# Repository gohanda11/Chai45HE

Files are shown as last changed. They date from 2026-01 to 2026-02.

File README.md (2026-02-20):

# Chai45HE

Chai45HE is a 40% Hall-effect keyboard based on the [HE60](https://github.com/peppapighs/HE60) project. This is a modified version that adapts the original 60% design to a compact 40% layout.

## Key Features

- 40% compact layout
- Hall-effect magnetic switches support
- Based on HE60's proven design and technology
- Custom PCB design files included

## ファームウェアの書き込み方法

1. [firmware.bin](firmware/firmware.bin) をダウンロードします。
2. 基板裏側の **BOOT** ボタンを長押ししながらUSBケーブルを接続し、Bootloader Modeに入ります。
3. [WebDFU](https://devanlai.github.io/webdfu/dfu-util/) にアクセスし、**DFU in FS mode** に接続します。
4. **Firmware Download** セクションでダウンロードした `firmware.bin` ファイルを選択します。
5. **Download** ボタンを押して書き込みを実行します。

## キー設定ガイド

### Tap-Holdの設定方法

Tap-Holdを使うと、短押し(Tap)と長押し(Hold)で異なるキーを割り当てることができます。

1. Remapで **Tap** に設定したいキーを配置します。
2. **Advanced Keys** から **Tap-Hold** を選択します。
3. **Hold** に設定したいキーを選択し、**Continue** を押します。
4. Hold用のキーを設定して **Done** で設定完了です。

### !@#$%などの記号キーの設定方法

Shiftキーとの組み合わせで入力される記号(!@#$%など)を単独のキーとして設定する方法です。

1. Remapで `1 2 3 4 5` を、`! @ # $ %` を入力したいキーに設定します。
2. **Advanced Keys** から **Dynamic Keystroke** を選択します。
3. 下の画像のようにShiftを割り当てます。

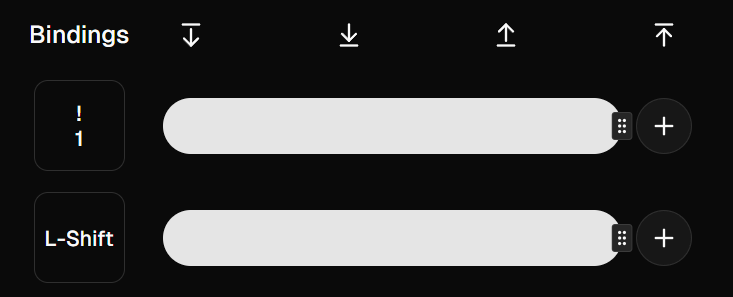
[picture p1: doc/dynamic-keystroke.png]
Dynamic Keystrokeの設定例
   

4. **Done** で設定完了です。

---

# HE60 (Original Project)

Below is the original README from the HE60 project, which this keyboard is based on.

---

# HE60

HE60 is a 60% Hall-effect keyboard PCB with 8kHz polling rate, a split spacebar and Tsangan layout support.

## Features

- Support for GH60 tray mount cases e.g., KBDfans Tofu60 Redux, and KBDfans Holy60.
- Support for gummy O-ring mount cases **if the USB-C port is not soldered** e.g., Bakeneko60, and SingaKBD Unikorn (required 10mm JST cable).
- [libhmk](https://github.com/peppapighs/libhmk) firmware.
- [hmkconf](https://hmk.prasertsuk.com) web-based configurator.

## Disclaimer

- The PCB requires standoffs to be mounted to the switch plate. The mounting points are **not compatible** with other available plates e.g., GEON Venom60 7U plate. HE60 v1 plate **is not compatible** with this PCB.

## Supported Layouts

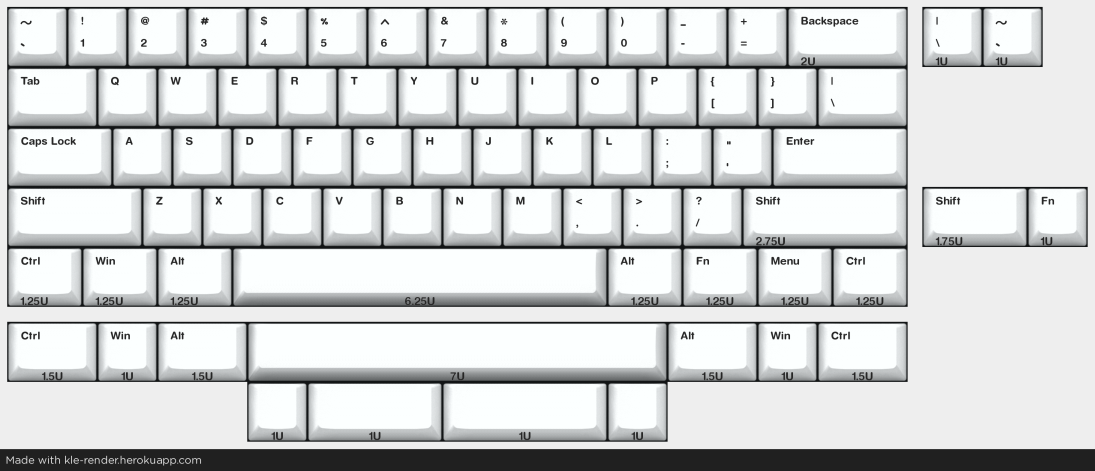
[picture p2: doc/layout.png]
Layouts


## Fabrication

The following files are required:

- BOM (Bill of Materials): Contains the list of components required to build the PCB.
- Pick and Place: Contains the placement of the components on the PCB.
- Gerber: Contains the PCB design files for fabrication.

Note that the components in the BOM are all mounted on the bottom side of the PCB, and are based on the available components in JLCPCB at the time of writing. You may need to adjust the components based on your preference or availability. For the JST connector (labeled `JST_SH`), I used `WAFER-SH1.0-4PWB` offered by JLCPCB. **Make sure to deselect the USB-C port when choosing the components to solder if you are using the gummy O-ring version.**

You may change the Hall-effect sensors during the component selection based on your preference, and availability. Different sensors require different calibration values, which can be adjusted using the web-based configurator. Here are some options that I have used:

- GH39FKSW (Cheapest)
- MT9102ET
- SS39ET
- DRV5055A3
- OH49E-S (Discontinued)

The fabrication files above are available [here](https://github.com/peppapighs/HE60/releases).

## Build Guide

The following items are required to build the PCB:

- PCB
- Switch plate (DXF file available [here](/plate.dxf). You may need to use less flexible materials such as aluminum or FR4 to prevent the switch at the top right corner from popping out if you use the alternative backspace layout. If you would like to manufacture FR4 plate along with the PCB, you can find the GERBER file for the plate [here](https://github.com/peppapighs/HE60/releases).)
- Magnetic switches (e.g., GEON Raw HE, Gateron Magnetic Jade, Duhuk Core HE, etc.)
- Stabilizers (**Clip-in stabilizers are required for the gummy O-ring version**)
- M2 3.5mm standoffs x8
- M2 3mm flat head screws x16

1. Install the stabilizers to the PCB.

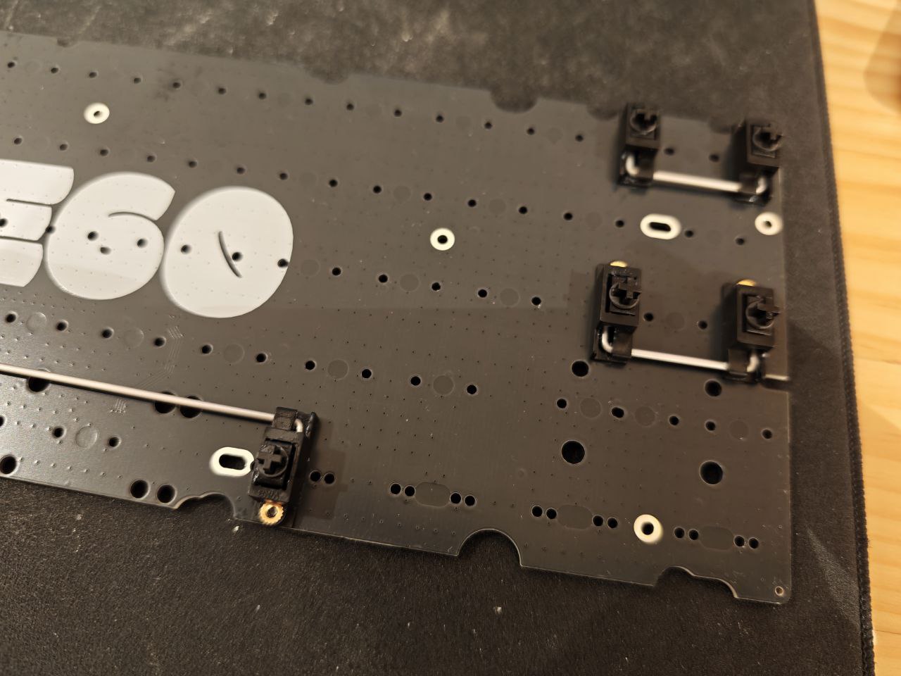
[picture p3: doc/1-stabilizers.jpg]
Stabilizers


2. Attach the standoffs to the PCB using the M2 screws.

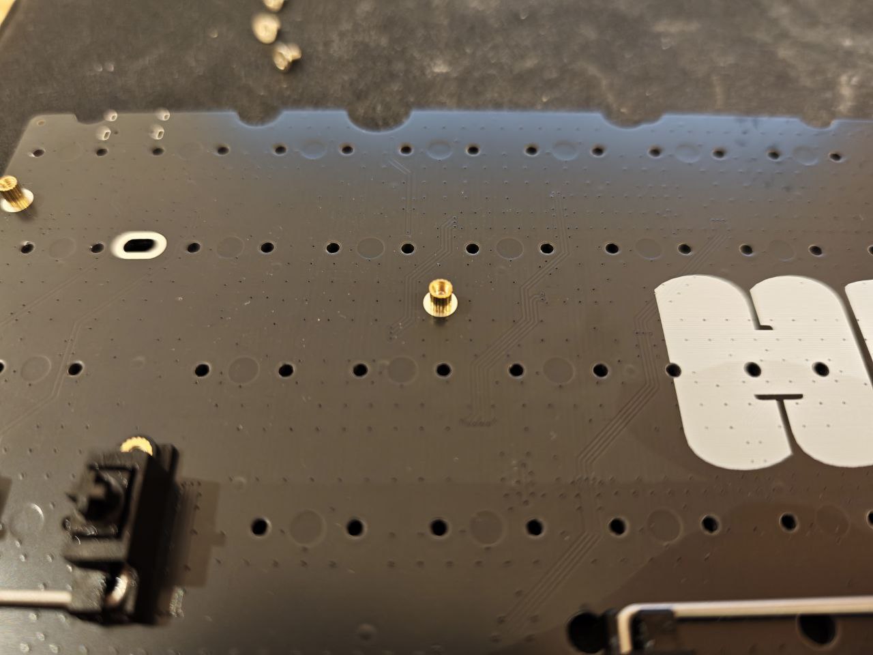
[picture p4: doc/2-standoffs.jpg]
Standoff


3. Install the switches to the plate. Assemble the plate and PCB together. Press the PCB against the plate to make sure the switches are seated properly. Screw the standoffs to the plate using the rest of the M2 screws.

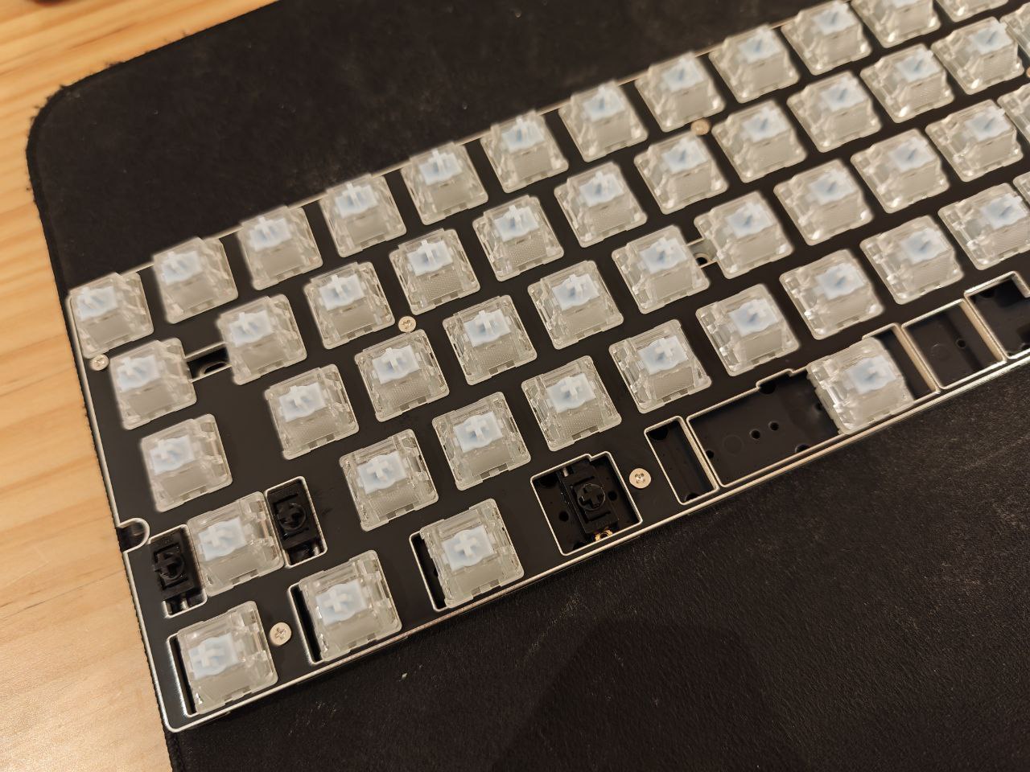
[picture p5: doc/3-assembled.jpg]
Assembled


4. Install the PCB into the case.

Case with keycaps

## Firmware

Head to [libhmk](https://github.com/peppapighs/libhmk/releases) for a pre-compiled firmware. The firmware can be flashed using DFU mode, which can be entered by holding the BOOT button before plugging in. You may need to install the DFU bootloader driver using Zadig. See [libhmk](https://github.com/peppapighs/libhmk) for more information for firmware flashing instructions.

## Acknowledgements

- Xelus from AEBoards for reviewing the PCB design and providing feedback.
- Keyboard Atelier community for supporting the project.

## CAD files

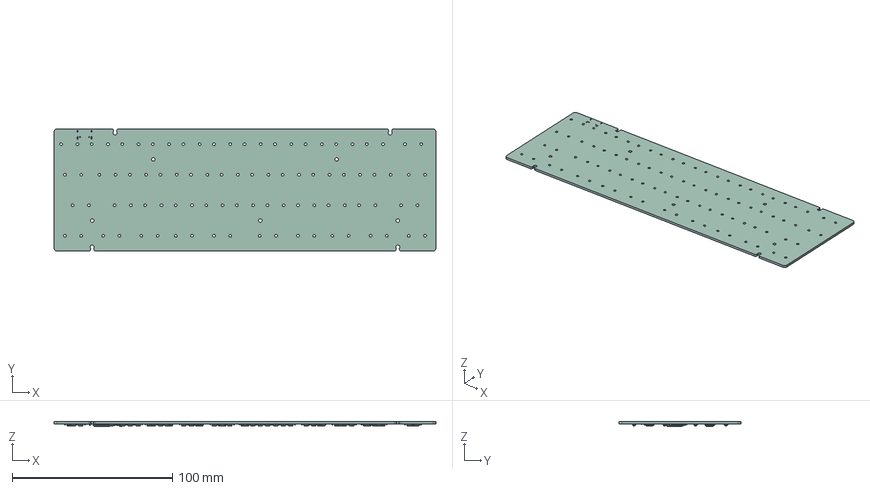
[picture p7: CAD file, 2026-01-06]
Chai45HE/Chai45HE.step
238.1 x 76.2 x 3.15 mm
SOT-23-3 x 46
C_0402_1005Metric x 101
LQFP-64_10x10mm_P0.5mm
TSSOP-16_4.4x5mm_P0.65mm x 6
C_0603_1608Metric x 8
R_0402_1005Metric x 4
Fuse_0805_2012Metric
SOT-23-5
Crystal_SMD_3225-4Pin_3.2x2.5mm
SOT-23-6
Chai45HE_PCB

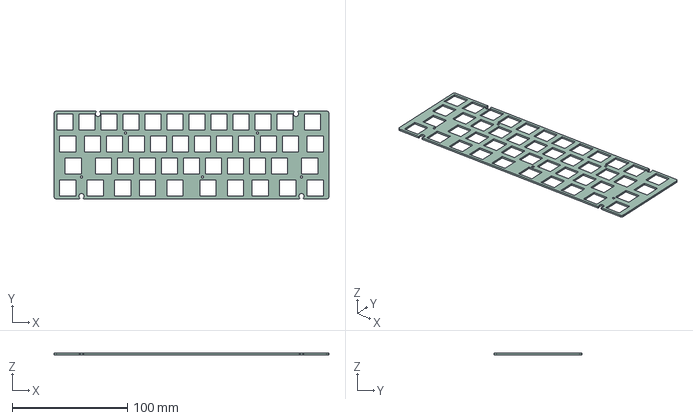
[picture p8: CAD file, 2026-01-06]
plate/switch/switch_plate.stp
238.1 x 76.2 x 1.50 mm

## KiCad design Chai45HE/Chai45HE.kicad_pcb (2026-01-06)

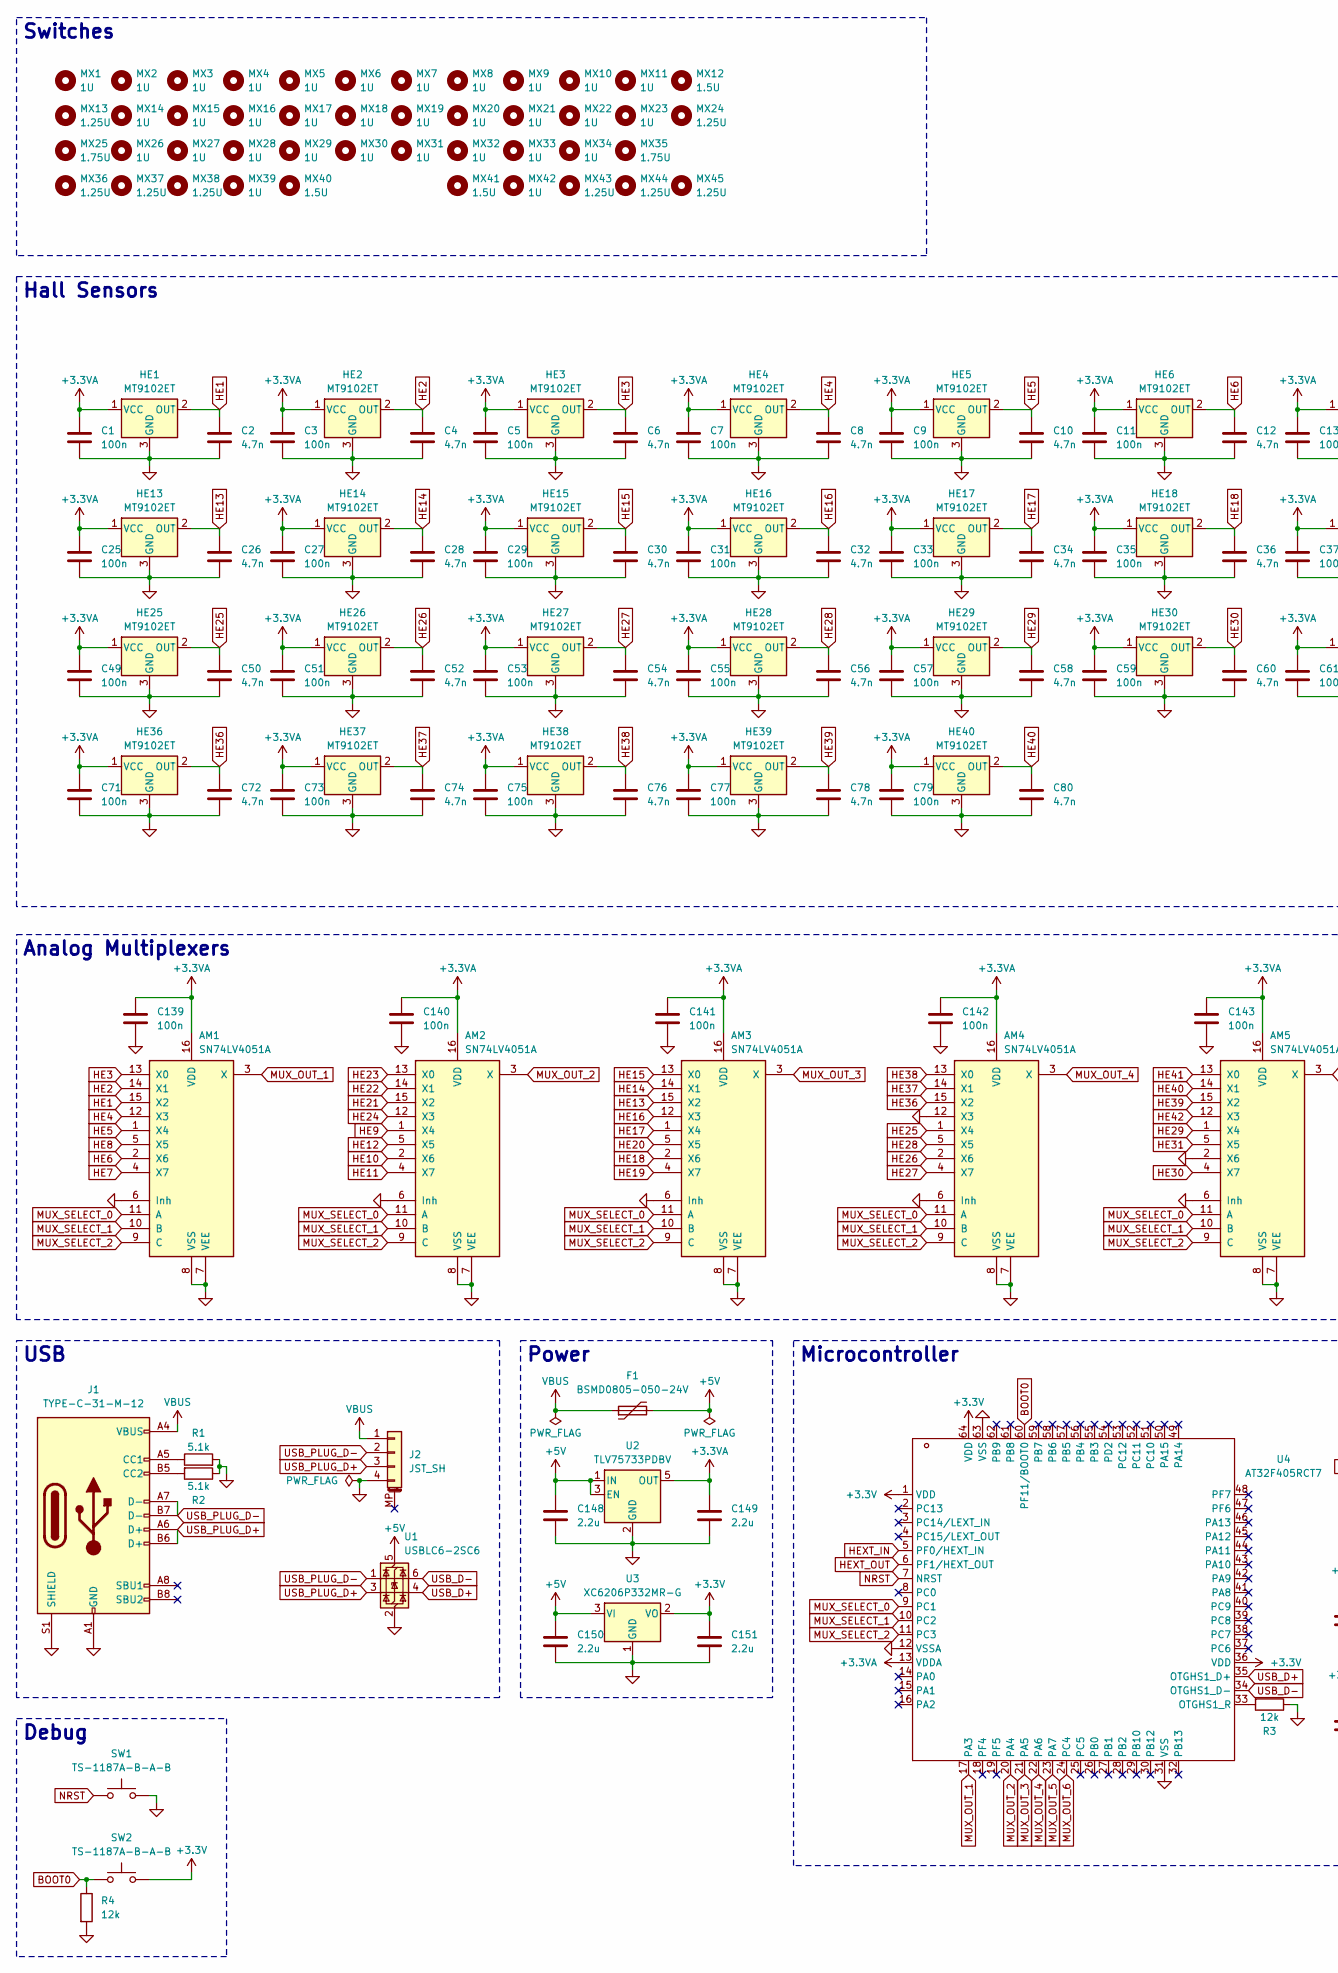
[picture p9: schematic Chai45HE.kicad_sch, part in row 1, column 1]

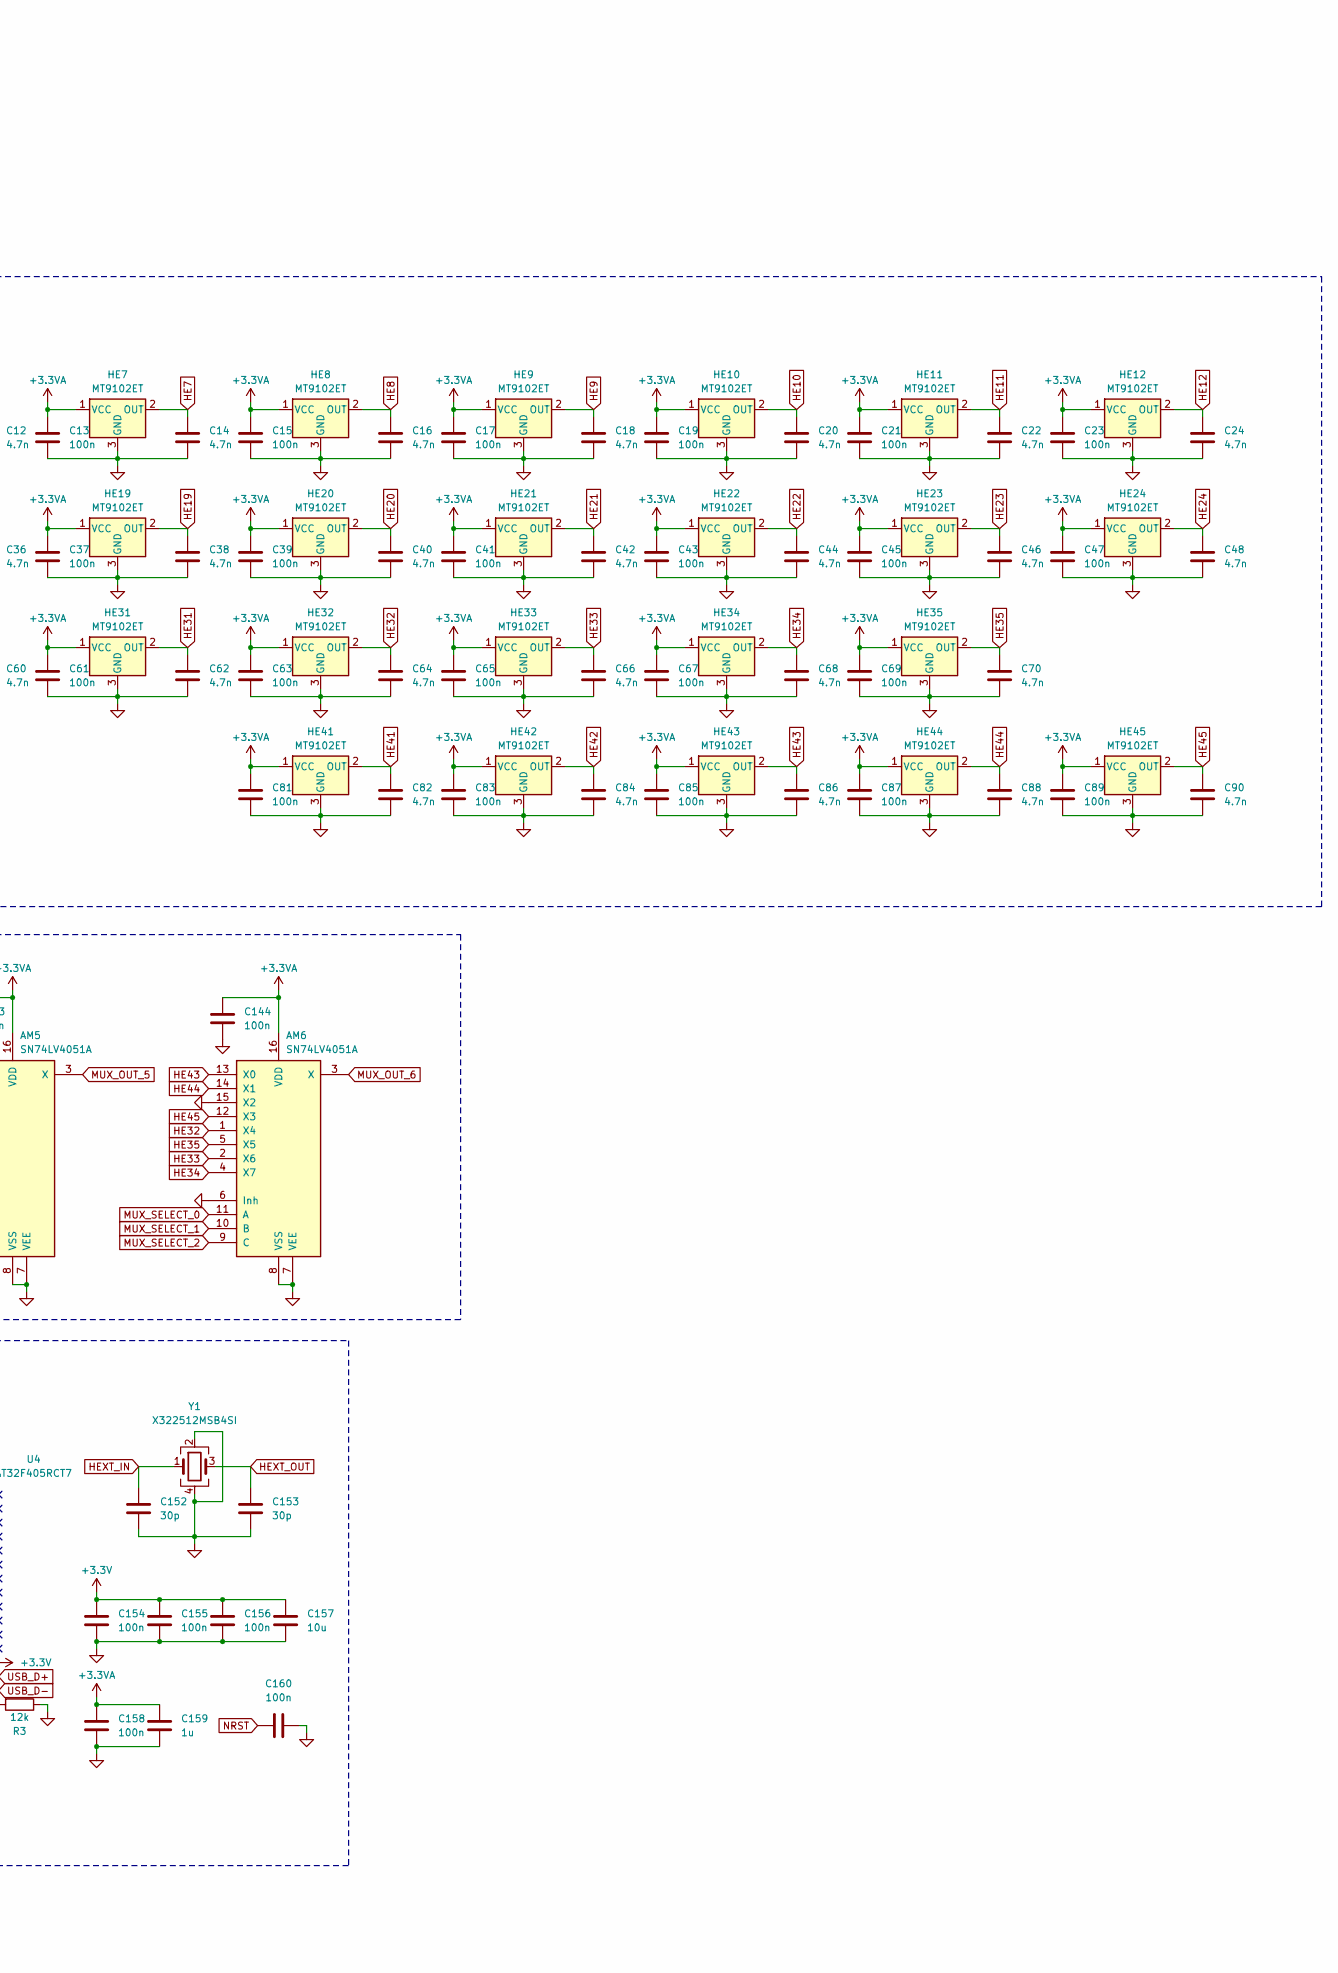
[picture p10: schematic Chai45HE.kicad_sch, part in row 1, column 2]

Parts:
AM1, AM2, AM3, AM4, AM5, AM6: SN74LV4051A; TSSOP-16_4.4x5mm_P0.65mm
C1, C3, C5, C7, C9, C11, C13, C15, C17, C19, C21, C23, C25, C27, C29, C31, C33, C35, C37, C39, C41, C43, C45, C47, C49, C51, C53, C55, C57, C59, C61, C63, C65, C67, C69, C71, C73, C75, C77, C79, C81, C83, C85, C87, C89, C139, C140, C141, C142, C143, C144, C154, C155, C156, C158, C160: 100n; C_0402_1005Metric
C2, C4, C6, C8, C10, C12, C14, C16, C18, C20, C22, C24, C26, C28, C30, C32, C34, C36, C38, C40, C42, C44, C46, C48, C50, C52, C54, C56, C58, C60, C62, C64, C66, C68, C70, C72, C74, C76, C78, C80, C82, C84, C86, C88, C90: 4.7n; C_0402_1005Metric
C148, C149, C150, C151: 2.2u; C_0603_1608Metric
C152, C153: 30p; C_0603_1608Metric
C157: 10u; C_0603_1608Metric
C159: 1u; C_0603_1608Metric
F1: BSMD0805-050-24V; Fuse_0805_2012Metric
HE1, HE2, HE3, HE4, HE5, HE6, HE7, HE8, HE9, HE10, HE11, HE12, HE13, HE14, HE15, HE16, HE17, HE18, HE19, HE20, HE21, HE22, HE23, HE24, HE25, HE26, HE27, HE28, HE29, HE30, HE31, HE32, HE33, HE34, HE35, HE36, HE37, HE38, HE39, HE40, HE41, HE42, HE43, HE44, HE45: MT9102ET; SOT-23-3
J1: TYPE-C-31-M-12; USB_C_Receptacle_HRO_TYPE-C-31-M-12
J2: JST_SH; JST_SH_SM04B-SRSS-TB_1x04-1MP_P1.00mm_Horizontal
MX1, MX2, MX3, MX4, MX5, MX6, MX7, MX8, MX9, MX10, MX11, MX14, MX15, MX16, MX17, MX18, MX19, MX20, MX21, MX22, MX23, MX26, MX27, MX28, MX29, MX30, MX31, MX32, MX33, MX34, MX39, MX42: 1U; MX-1U
MX12, MX40, MX41: 1.5U; MX-1.5U
MX13, MX24, MX36, MX37, MX38, MX43, MX44, MX45: 1.25U; MX-1.25U
MX25, MX35: 1.75U; MX-1.75U
R1, R2: 5.1k; R_0402_1005Metric
R3, R4: 12k; R_0402_1005Metric
SW1, SW2: TS-1187A-B-A-B; SW_Push_1P1T_XKB_TS-1187A
U1: USBLC6-2SC6; SOT-23-6
U2: TLV75733PDBV; SOT-23-5
U3: XC6206P332MR-G; SOT-23-3
U4: AT32F405RCT7; LQFP-64_10x10mm_P0.5mm
Y1: X322512MSB4SI; Crystal_SMD_3225-4Pin_3.2x2.5mm

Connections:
+3.3V: C151.1, C154.1, C155.1, C156.1, C157.1, SW2.2, U3.2 (VO), U4.1 (VDD), U4.36 (VDD), U4.64 (VDD)
+3.3VA: AM1.16 (VDD), AM2.16 (VDD), AM3.16 (VDD), AM4.16 (VDD), AM5.16 (VDD), AM6.16 (VDD), C1.1, C3.1, C5.1, C7.1, C9.1, C11.1, C13.1, C15.1, C17.1, C19.1, C21.1, C23.1, C25.1, C27.1, C29.1, C31.1, C33.1, C35.1, C37.1, C39.1, C41.1, C43.1, C45.1, C47.1, C49.1, C51.1, C53.1, C55.1, C57.1, C59.1, C61.1, C63.1, C65.1, C67.1, C69.1, C71.1, C73.1, C75.1, C77.1, C79.1, C81.1, C83.1, C85.1, C87.1, C89.1, C139.1, C140.1, C141.1, C142.1, C143.1, C144.1, C149.1, C158.1, C159.1, HE1.1 (VCC), HE2.1 (VCC), HE3.1 (VCC), HE4.1 (VCC), HE5.1 (VCC), HE6.1 (VCC), HE7.1 (VCC), HE8.1 (VCC), HE9.1 (VCC), HE10.1 (VCC), HE11.1 (VCC), HE12.1 (VCC), HE13.1 (VCC), HE14.1 (VCC), HE15.1 (VCC), HE16.1 (VCC), HE17.1 (VCC), HE18.1 (VCC), HE19.1 (VCC), HE20.1 (VCC), HE21.1 (VCC), HE22.1 (VCC), HE23.1 (VCC), HE24.1 (VCC), HE25.1 (VCC), HE26.1 (VCC), HE27.1 (VCC), HE28.1 (VCC), HE29.1 (VCC), HE30.1 (VCC), HE31.1 (VCC), HE32.1 (VCC), HE33.1 (VCC), HE34.1 (VCC), HE35.1 (VCC), HE36.1 (VCC), HE37.1 (VCC), HE38.1 (VCC), HE39.1 (VCC), HE40.1 (VCC), HE41.1 (VCC), HE42.1 (VCC), HE43.1 (VCC), HE44.1 (VCC), HE45.1 (VCC), U2.5 (OUT), U4.13 (VDDA)
+5V: C148.1, C150.1, F1.2, U1.5 (VBUS), U2.1 (IN), U2.3 (EN), U3.3 (VI)
BOOT0: R4.1, SW2.1, U4.60 (PF11/BOOT0)
GND: AM1.6 (Inh), AM1.7 (VEE), AM1.8 (VSS), AM2.6 (Inh), AM2.7 (VEE), AM2.8 (VSS), AM3.6 (Inh), AM3.7 (VEE), AM3.8 (VSS), AM4.6 (Inh), AM4.7 (VEE), AM4.8 (VSS), AM4.12 (X3), AM5.2 (X6), AM5.6 (Inh), AM5.7 (VEE), AM5.8 (VSS), AM6.6 (Inh), AM6.7 (VEE), AM6.8 (VSS), AM6.15 (X2), C1.2, C2.2, C3.2, C4.2, C5.2, C6.2, C7.2, C8.2, C9.2, C10.2, C11.2, C12.2, C13.2, C14.2, C15.2, C16.2, C17.2, C18.2, C19.2, C20.2, C21.2, C22.2, C23.2, C24.2, C25.2, C26.2, C27.2, C28.2, C29.2, C30.2, C31.2, C32.2, C33.2, C34.2, C35.2, C36.2, C37.2, C38.2, C39.2, C40.2, C41.2, C42.2, C43.2, C44.2, C45.2, C46.2, C47.2, C48.2, C49.2, C50.2, C51.2, C52.2, C53.2, C54.2, C55.2, C56.2, C57.2, C58.2, C59.2, C60.2, C61.2, C62.2, C63.2, C64.2, C65.2, C66.2, C67.2, C68.2, C69.2, C70.2, C71.2, C72.2, C73.2, C74.2, C75.2, C76.2, C77.2, C78.2, C79.2, C80.2, C81.2, C82.2, C83.2, C84.2, C85.2, C86.2, C87.2, C88.2, C89.2, C90.2, C139.2, C140.2, C141.2, C142.2, C143.2, C144.2, C148.2, C149.2, C150.2, C151.2, C152.2, C153.2, C154.2, C155.2, C156.2, C157.2, C158.2, C159.2, C160.2, HE1.3 (GND), HE2.3 (GND), HE3.3 (GND), HE4.3 (GND), HE5.3 (GND), HE6.3 (GND), HE7.3 (GND), HE8.3 (GND), HE9.3 (GND), HE10.3 (GND), HE11.3 (GND), HE12.3 (GND), HE13.3 (GND), HE14.3 (GND), HE15.3 (GND), HE16.3 (GND), HE17.3 (GND), HE18.3 (GND), HE19.3 (GND), HE20.3 (GND), HE21.3 (GND), HE22.3 (GND), HE23.3 (GND), HE24.3 (GND), HE25.3 (GND), HE26.3 (GND), HE27.3 (GND), HE28.3 (GND), HE29.3 (GND), HE30.3 (GND), HE31.3 (GND), HE32.3 (GND), HE33.3 (GND), HE34.3 (GND), HE35.3 (GND), HE36.3 (GND), HE37.3 (GND), HE38.3 (GND), HE39.3 (GND), HE40.3 (GND), HE41.3 (GND), HE42.3 (GND), HE43.3 (GND), HE44.3 (GND), HE45.3 (GND), J1.A1 (GND), J1.A12 (GND), J1.B1 (GND), J1.B12 (GND), J1.S1 (SHIELD), J2.4, R1.2, R2.1, R3.1, R4.2, SW1.2, U1.2 (GND), U2.2 (GND), U3.1 (GND), U4.12 (VSSA), U4.31 (VSS), U4.63 (VSS), Y1.2, Y1.4
HE1: AM1.15 (X2), C2.1, HE1.2 (OUT)
HE2: AM1.14 (X1), C4.1, HE2.2 (OUT)
HE3: AM1.13 (X0), C6.1, HE3.2 (OUT)
HE4: AM1.12 (X3), C8.1, HE4.2 (OUT)
HE5: AM1.1 (X4), C10.1, HE5.2 (OUT)
HE6: AM1.2 (X6), C12.1, HE6.2 (OUT)
HE7: AM1.4 (X7), C14.1, HE7.2 (OUT)
HE8: AM1.5 (X5), C16.1, HE8.2 (OUT)
HE9: AM2.1 (X4), C18.1, HE9.2 (OUT)
HE10: AM2.2 (X6), C20.1, HE10.2 (OUT)
HE11: AM2.4 (X7), C22.1, HE11.2 (OUT)
HE12: AM2.5 (X5), C24.1, HE12.2 (OUT)
HE13: AM3.15 (X2), C26.1, HE13.2 (OUT)
HE14: AM3.14 (X1), C28.1, HE14.2 (OUT)
HE15: AM3.13 (X0), C30.1, HE15.2 (OUT)
HE16: AM3.12 (X3), C32.1, HE16.2 (OUT)
HE17: AM3.1 (X4), C34.1, HE17.2 (OUT)
HE18: AM3.2 (X6), C36.1, HE18.2 (OUT)
HE19: AM3.4 (X7), C38.1, HE19.2 (OUT)
HE20: AM3.5 (X5), C40.1, HE20.2 (OUT)
HE21: AM2.15 (X2), C42.1, HE21.2 (OUT)
HE22: AM2.14 (X1), C44.1, HE22.2 (OUT)
HE23: AM2.13 (X0), C46.1, HE23.2 (OUT)
HE24: AM2.12 (X3), C48.1, HE24.2 (OUT)
HE25: AM4.1 (X4), C50.1, HE25.2 (OUT)
HE26: AM4.2 (X6), C52.1, HE26.2 (OUT)
HE27: AM4.4 (X7), C54.1, HE27.2 (OUT)
HE28: AM4.5 (X5), C56.1, HE28.2 (OUT)
HE29: AM5.1 (X4), C58.1, HE29.2 (OUT)
HE30: AM5.4 (X7), C60.1, HE30.2 (OUT)
HE31: AM5.5 (X5), C62.1, HE31.2 (OUT)
HE32: AM6.1 (X4), C64.1, HE32.2 (OUT)
HE33: AM6.2 (X6), C66.1, HE33.2 (OUT)
HE34: AM6.4 (X7), C68.1, HE34.2 (OUT)
HE35: AM6.5 (X5), C70.1, HE35.2 (OUT)
HE36: AM4.15 (X2), C72.1, HE36.2 (OUT)
HE37: AM4.14 (X1), C74.1, HE37.2 (OUT)
HE38: AM4.13 (X0), C76.1, HE38.2 (OUT)
HE39: AM5.15 (X2), C78.1, HE39.2 (OUT)
HE40: AM5.14 (X1), C80.1, HE40.2 (OUT)
HE41: AM5.13 (X0), C82.1, HE41.2 (OUT)
HE42: AM5.12 (X3), C84.1, HE42.2 (OUT)
HE43: AM6.13 (X0), C86.1, HE43.2 (OUT)
HE44: AM6.14 (X1), C88.1, HE44.2 (OUT)
HE45: AM6.12 (X3), C90.1, HE45.2 (OUT)
HEXT_IN: C152.1, U4.5 (PF0/HEXT_IN), Y1.1
HEXT_OUT: C153.1, U4.6 (PF1/HEXT_OUT), Y1.3
MUX_OUT_1: AM1.3 (X), U4.17 (PA3)
MUX_OUT_2: AM2.3 (X), U4.20 (PA4)
MUX_OUT_3: AM3.3 (X), U4.21 (PA5)
MUX_OUT_4: AM4.3 (X), U4.22 (PA6)
MUX_OUT_5: AM5.3 (X), U4.23 (PA7)
MUX_OUT_6: AM6.3 (X), U4.24 (PC4)
MUX_SELECT_0: AM1.11 (A), AM2.11 (A), AM3.11 (A), AM4.11 (A), AM5.11 (A), AM6.11 (A), U4.9 (PC1)
MUX_SELECT_1: AM1.10 (B), AM2.10 (B), AM3.10 (B), AM4.10 (B), AM5.10 (B), AM6.10 (B), U4.10 (PC2)
MUX_SELECT_2: AM1.9 (C), AM2.9 (C), AM3.9 (C), AM4.9 (C), AM5.9 (C), AM6.9 (C), U4.11 (PC3)
NRST: C160.1, SW1.1, U4.7 (NRST)
unnamed: J1.A5 (CC1), R1.1
unnamed: J1.B5 (CC2), R2.2
unnamed: R3.2, U4.33 (OTGHS1_R)
USB_D+: U1.4 (I/O2), U4.35 (OTGHS1_D+)
USB_D-: U1.6 (I/O1), U4.34 (OTGHS1_D-)
USB_PLUG_D+: J1.A6 (D+), J1.B6 (D+), J2.3, U1.3 (I/O2)
USB_PLUG_D-: J1.A7 (D-), J1.B7 (D-), J2.2, U1.1 (I/O1)
VBUS: F1.1, J1.A4 (VBUS), J1.A9 (VBUS), J1.B4 (VBUS), J1.B9 (VBUS), J2.1

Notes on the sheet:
Hall Sensors
Switches
USB
Analog Multiplexers
Power
Debug
Microcontroller

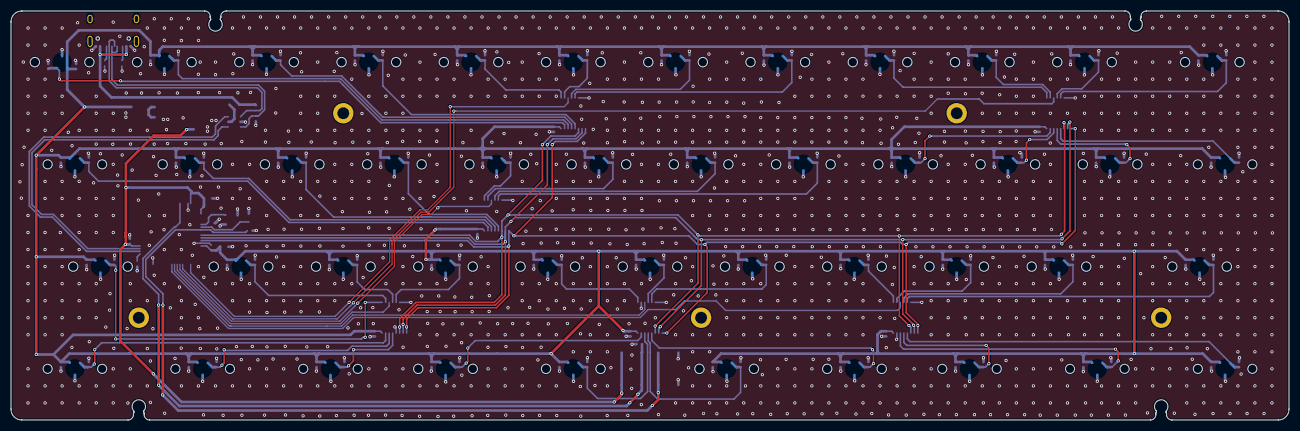
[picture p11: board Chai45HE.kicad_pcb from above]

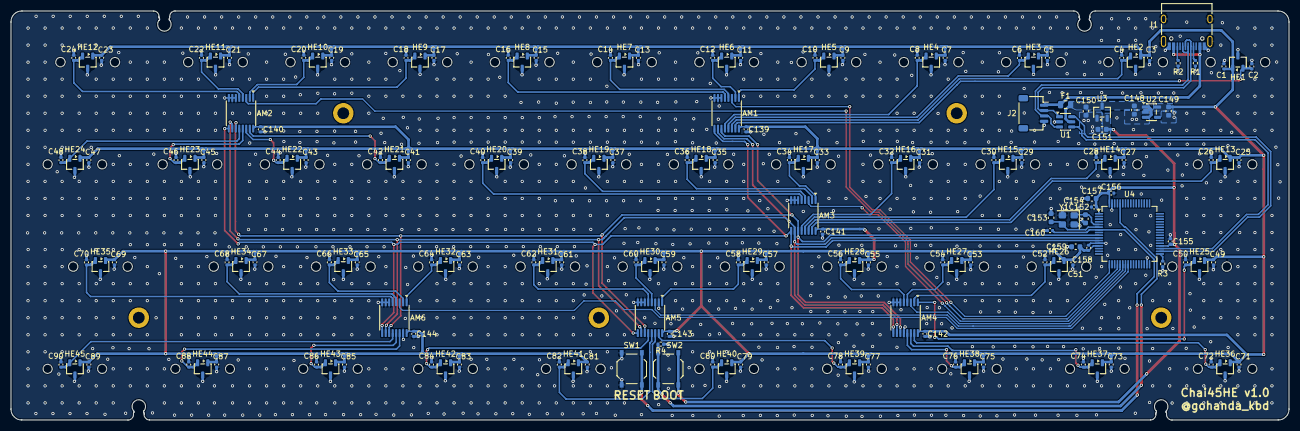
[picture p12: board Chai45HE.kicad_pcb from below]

Board: 2 copper layers, 238.1 x 76.2 mm, 219 parts (174 on the bottom side), 70 nets.

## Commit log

2026-01-06 Add Chai45HE specific files to .gitignore
    Added the following files and directories to .gitignore:
    - case.stp
    - plate/bottom, plate/form_bottom
    - Chai45HE/plasticity/, Chai45HE/chai45he.plasticity, Chai45HE/production/
    - form_bottom.stp, form_middle.stp
    - layout.json
2026-01-06 Remove case.stp from Git tracking
    This file is now ignored via .gitignore but remains in the local directory.
    [case.stp]
2026-01-06 Remove 3D case design files mention from README
2026-02-20 READMEにファームウェアダウンロードの手順を追加
2026-02-20 gitignoreとファームウェアを追加
